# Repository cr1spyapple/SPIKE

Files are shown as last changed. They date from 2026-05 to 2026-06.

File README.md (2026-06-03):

# SPIKE
A sleek and speedy ESP32-S3 powered development board

Designed in KiCAD as part of STASIS for Hack Club. I took up this project to learn more about PCB and MCU design. This acts as a prototype of sorts to my e-Reader project <a href="https://github.com/cr1spyapple/Bebop">"Bebop"</a> which will use similar hardware to this.

## Specs:
- 32 GPIO pins
- 16MB flash
- 8MB PSRAM
- WiFi and Bluetooth connectivity
- USB-C port

## PCB Model
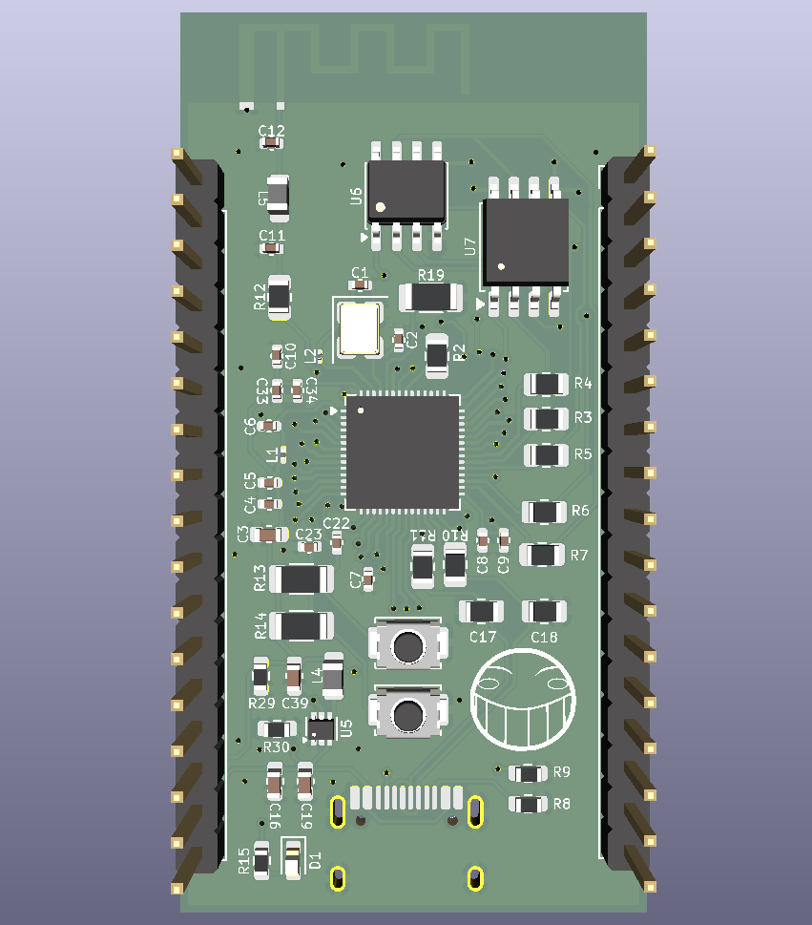
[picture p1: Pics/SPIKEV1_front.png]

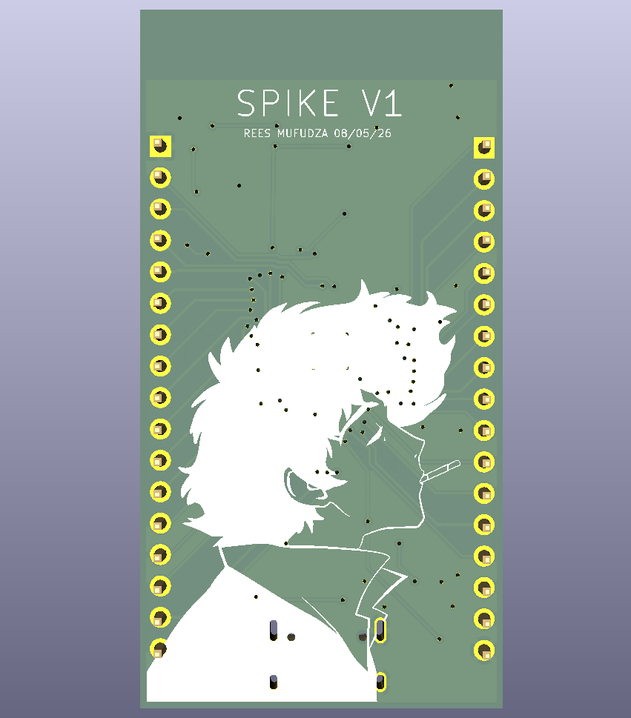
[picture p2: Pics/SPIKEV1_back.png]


## Schematic
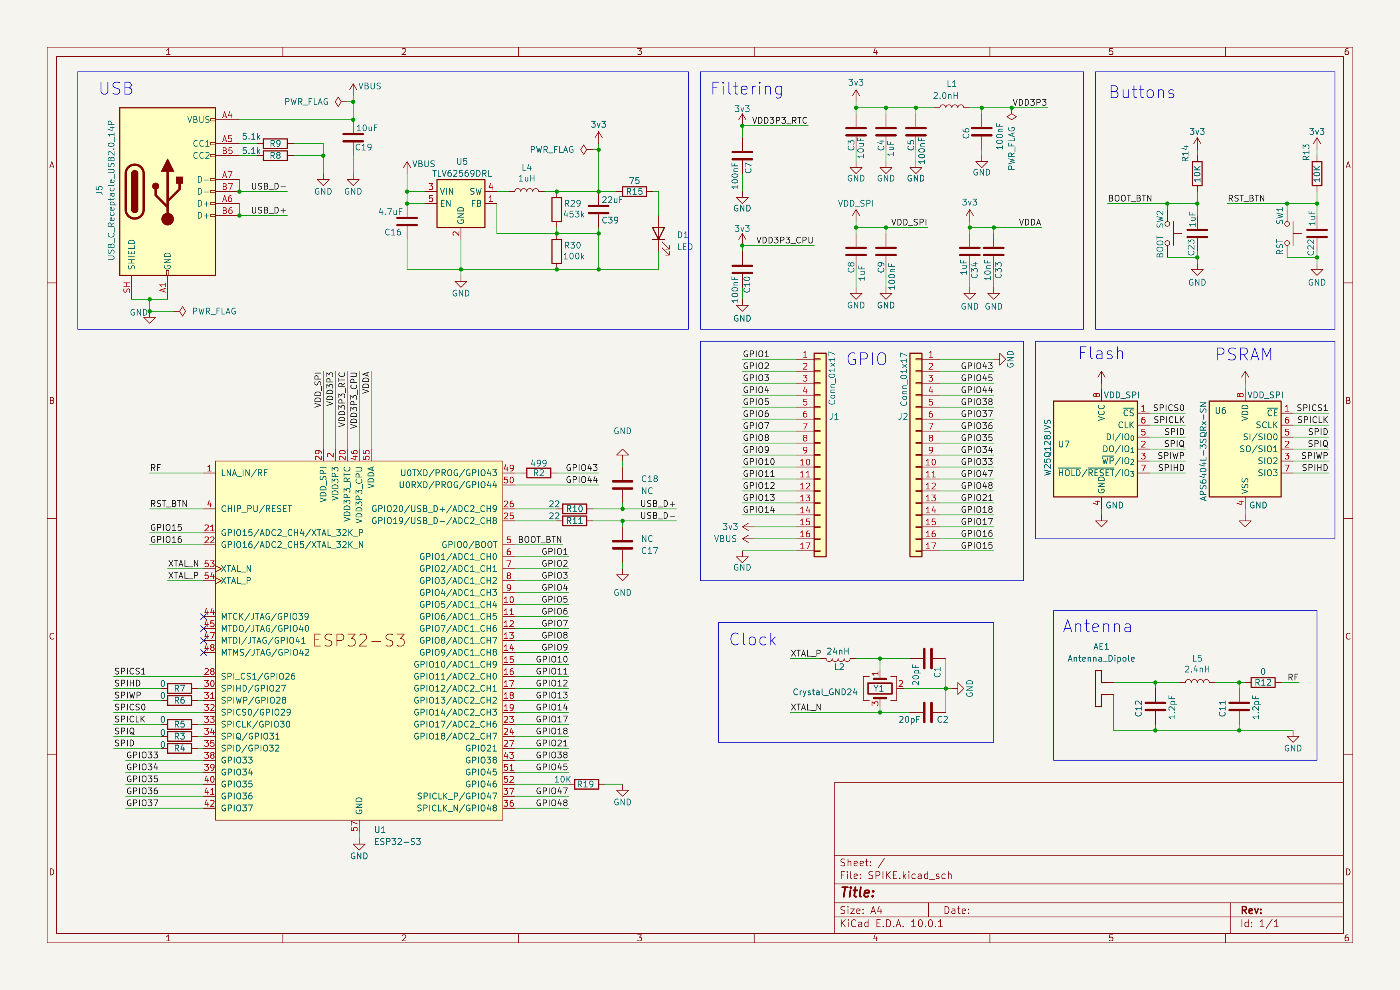
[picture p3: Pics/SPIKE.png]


## PCB Traces
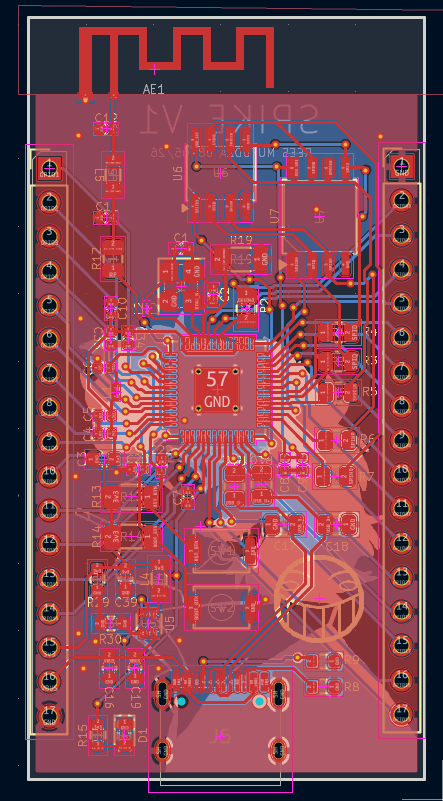
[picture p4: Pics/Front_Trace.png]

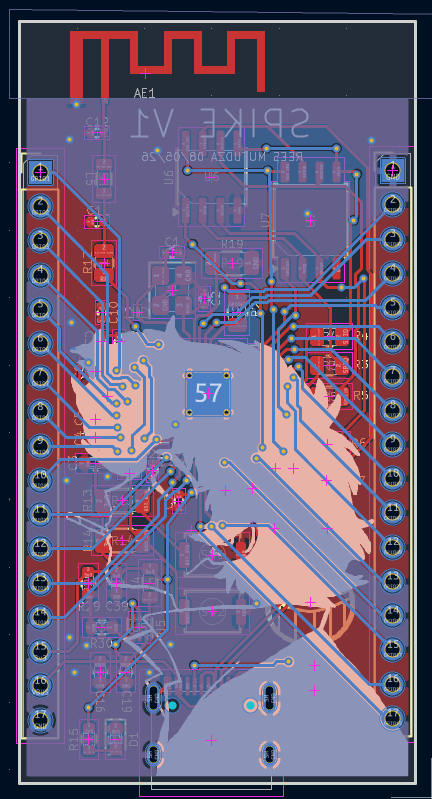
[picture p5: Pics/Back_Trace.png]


## Bill of Materials

|Name |Purpose |Quantity|Total Cost (USD)|Link |Distributor|
|---|---|---|---|---|---|
|10kΩ ±5% 100mW 0603 Thick Film Resistor | |100 |0.11 |https://www.lcsc.com/product-detail/C2930027.html | |
|1.2pF 50V Ceramic Capacitor C0G 0402 | |50 |1.79 |https://www.lcsc.com/product-detail/C76899.html | |
|100nF ±10% 16V Ceramic Capacitor X7R 0402 | |100 |0.16 |https://www.lcsc.com/product-detail/C60474.html | |
|1uF ±10% 16V Ceramic Capacitor X5R 0402 | |100 |0.38 |https://www.lcsc.com/product-detail/C29266.html | |
|20pF ±5% 50V Ceramic Capacitor C0G 0402 | |100 |0.57 |https://www.lcsc.com/product-detail/C76959.html | |
|2.7V~3.6V 128Mbit 133MHz SPI SOIC-8-208mil Memory (ICs) RoHS | |3 |7.92 |https://www.lcsc.com/product-detail/C97521.html | |
|2A 1uH ±20% 95mΩ 3.1A 0805 Fixed Inductors RoHS | |5 |1.05 |https://www.lcsc.com/product-detail/C1331798.html | |
|140mA 24nH ±3% 2.3Ω Thick Film Inductor 0201 Fixed Inductors RoHS | |100 |0.84 |https://www.lcsc.com/product-detail/C206441.html | |
|500mA 2nH 100mΩ 0603 Fixed Inductors RoHS | |50 |0.65 |https://www.lcsc.com/product-detail/C395081.html | |
|USB-C (USB TYPE-C) Receptacle Connector 16 Position Surface Mount | |5 |0.94 |https://www.lcsc.com/product-detail/C165948.html | |
|Red 645nm LED Indication - Discrete 2.4V 0603 | |100 |0.70 |https://www.lcsc.com/product-detail/C2286.html | |
|22uF ±20% 10V Ceramic Capacitor X5R 0603 | |10 |0.21 |https://www.lcsc.com/product-detail/C86295.html | |
|10nF ±10% 50V Ceramic Capacitor X7R 0603 | |100 |0.37 |https://www.lcsc.com/product-detail/C100042.html | |
|499Ω ±1% 62.5mW 0402 Thick Film Resistor | |100 |0.07 |https://www.lcsc.com/product-detail/C4125.html | |
|800mA 2.4nH 80mΩ Multilayer inductor 0402 Fixed Inductors RoHS | |10 |0.10 |https://www.lcsc.com/product-detail/C275281.html | |
|10uF ±20% 25V Ceramic Capacitor X5R 0603 | |20 |0.61 |https://www.lcsc.com/product-detail/C96446.html | |
|Crystal 40MHz ±10ppm 15pF SMD3225-4P | |10 |0.69 |https://www.lcsc.com/product-detail/C5444549.html | |
|SOP-8L Memory (ICs) RoHS | |2 |8.93 |https://www.lcsc.com/product-detail/C3028887.html | |
|1.5MHz Step-down type Adjustable 600mV~5.5V 2A SOT-563 Voltage Regulators - DC DC Switching Regulators RoHS| |5 |0.59 |https://www.lcsc.com/product-detail/C163217.html | |
|-98.4dBm 150Mbps 2.412GHz~2.484GHz 2.4GHz 3V~3.6V QFN-56-EP(7x7) RF Transceiver ICs RoHS | |3 |9.06 |https://www.lcsc.com/product-detail/C2913192.html | |
|Tactile Switch SPST 160gf 2mm SMD (SMT) Tab 4mm x 3mm Surface Mount | |10 |0.57 |https://www.lcsc.com/product-detail/C720477.html | |
|100mW 100kΩ 75V Thick Film Resistor ±100ppm/℃ ±1% 0603 Chip Resistor - Surface Mount RoHS | |100 |0.15 |https://www.lcsc.com/product-detail/C14675.html | |
|453kΩ ±0.1% 100mW 0603 Thin Film Resistor | |20 |0.48 |https://www.lcsc.com/product-detail/C2686428.html | |
|75Ω ±1% 100mW 0603 Thick Film Resistor | |100 |0.19 |https://www.lcsc.com/product-detail/C4275.html | |
|22Ω ±5% 100mW 0603 Thick Film Resistor | |100 |0.12 |https://www.lcsc.com/product-detail/C2907129.html | |
|5.1kΩ ±1% 100mW 0603 Thick Film Resistor | |100 |0.13 |https://www.lcsc.com/product-detail/C2907044.html | |
|0Ω 125mW 200V Thick Film Resistor 0805 Chip Resistor - Surface Mount RoHS | |100 |0.63 |https://www.lcsc.com/product-detail/C844934.html | |
|4.7uF ±10% 16V Ceramic Capacitor X5R 0603 | |10 |0.14 |https://www.lcsc.com/product-detail/C19666.html | |
|Header pins |Header pins for PCB |1 |1.98 |https://www.aliexpress.com/item/1005008703085861.html?search_p4p_id=202605091107184238603551627500001818552_9|Aliexpress |
|Soldering paste (20g) |Soldering components |1 |3.46 |https://www.aliexpress.com/item/1005009377104599.html?mp=1 |Aliexpress |
|Hot Plate |Soldering SMD components  |1 |13.99 |https://www.aliexpress.com/item/1005007016135854.html?mp=1 |Aliexpress |
|65W Type-C power adapter |Power supply for Hot Plate|1 |12.68 |https://www.ebay.co.uk/itm/406309629830 |Ebay |
|PCB |PCB |5 |4.10 | |JLCPCB |

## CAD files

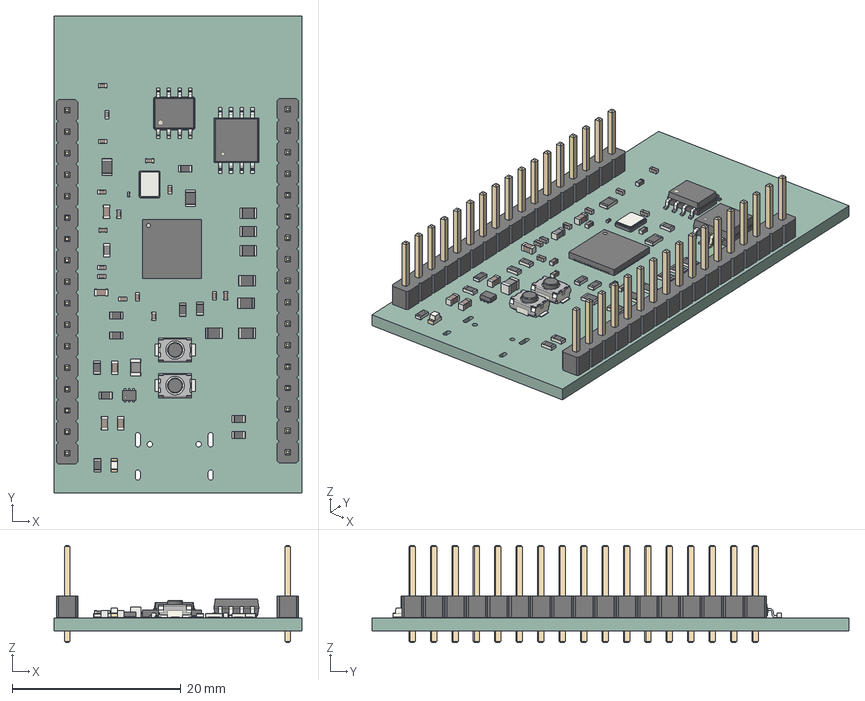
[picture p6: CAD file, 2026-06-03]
models/jett.step
29.3 x 56.5 x 11.5 mm
R_0805_2012Metric x 9
C_0603_1608Metric x 5
L_0805_2012Metric
R_0603_1608Metric x 10
a48c614c-8773-11ed-8f9d-58fb8493fcfb_part
a48c63fe-8773-11ed-8f9d-58fb8493fcfb_part
a48c65a2-8773-11ed-8f9d-58fb8493fcfb_part
a48c66d8-8773-11ed-8f9d-58fb8493fcfb_part
C_0402_1005Metric x 14
SW_Push_SPST_NO_Alps_SKRK x 2
LED_0603_1608Metric
L_0201_0603Metric
L_0603_1608Metric
PinHeader_1x17_P254mm_Vertical x 2
SOT_563
L_0402_1005Metric
Crystal_SMD_3225-4Pin_3.2x2.5mm
SOIC-8_3.9x4.9mm_P1.27mm
SOIC-8_5.3x5.3mm_P1.27mm
SPIKE_PCB

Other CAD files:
models/jett.stl

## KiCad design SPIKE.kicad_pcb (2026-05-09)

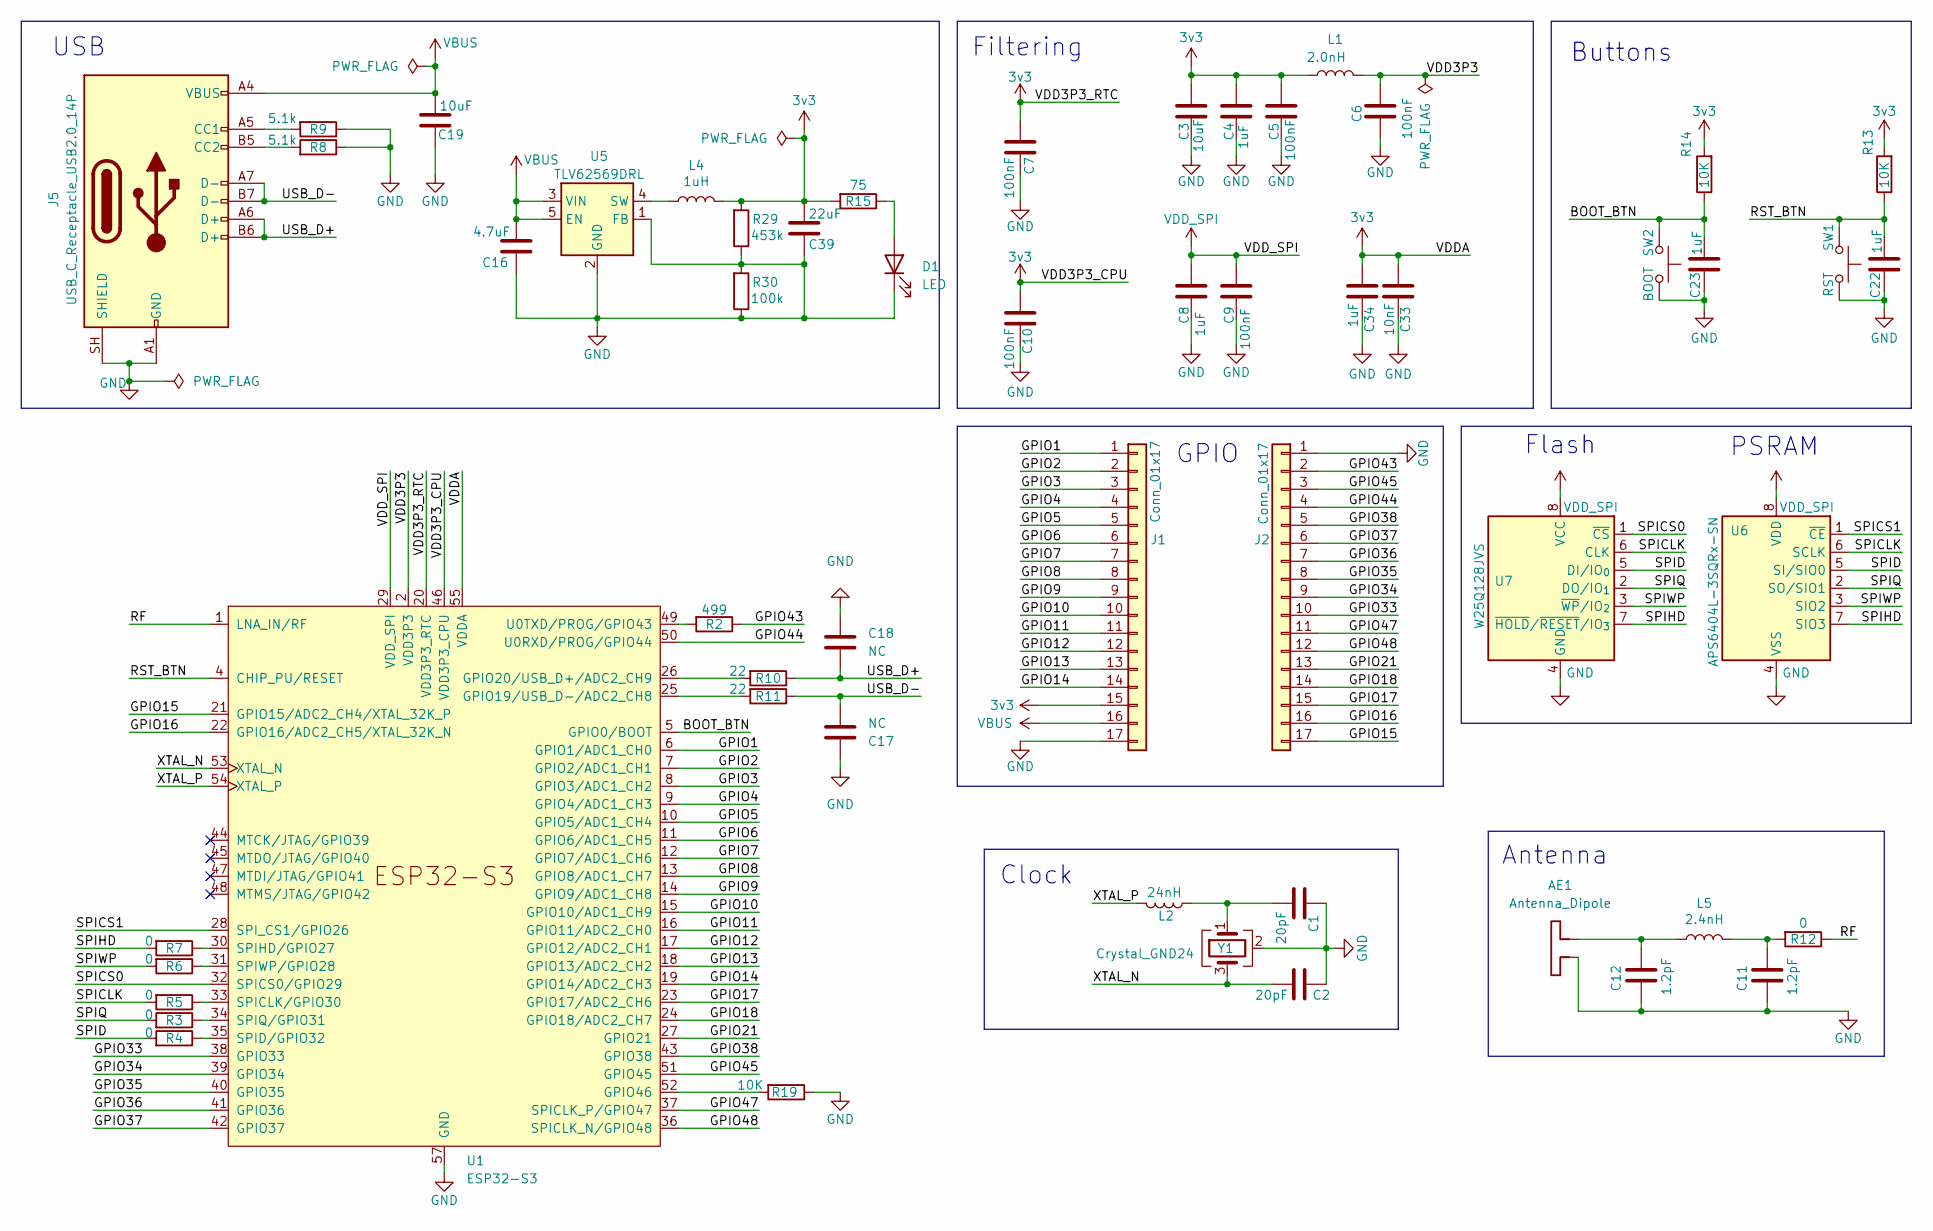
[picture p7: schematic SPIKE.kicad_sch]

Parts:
AE1: Antenna_Dipole; Trace Antenna 2.4GHz
C1, C2: 20pF; C_0402_1005Metric; MNF PART NUMBER C1554
C3, C19: 10uF; C_0603_1608Metric; MNF PART NUMBER C19702
C4, C8, C22, C23, C34: 1uF; C_0402_1005Metric; MNF PART NUMBER C52923
C5, C6, C7, C9, C10: 100nF; C_0402_1005Metric; MNF PART NUMBER C1591
C11, C12: 1.2pF; C_0402_1005Metric; MNF PART NUMBER C52923
C16: 4.7uF; C_0603_1608Metric; MNF PART NUMBER C19702
C17, C18: NC; R_0805_2012Metric
C33: 10nF; C_0603_1608Metric; MNF PART NUMBER C57112
C39: 22uF; C_0603_1608Metric; MNF PART NUMBER C19702
D1: LED; LED_0603_1608Metric; MFN PART NUMBER C2286
J1, J2: Conn_01x17; PinHeader_1x17_P2.54mm_Vertical
J5: USB_C_Receptacle_USB2.0_14P; USB_C_Receptacle_HRO_TYPE-C-31-M-12; MNF PART NUMBER C165948
L1: 2.0nH; L_0603_1608Metric; MNF PART NUMBER C370234
L2: 24nH; L_0201_0603Metric; MNF PART NUMBER C139271
L4: 1uH; L_0805_2012Metric; MNF PART NUMBER C19533
L5: 2.4nH; L_0805_2012Metric; MNF PART NUMBER C19533
R2: 499; R_0805_2012Metric; MNF PART NUMBER C17722
R3, R4, R5, R6, R7, R12: 0; R_0805_2012Metric; MNF PART NUMBER C17477
R8, R9: 5.1k; R_0603_1608Metric; MNF PART NUMBER C23186
R10, R11: 22; R_0603_1608Metric; MNF PART NUMBER C23345
R13, R14, R19: 10K; R_0603_1608Metric; MNF PART NUMBER C25804
R15: 75; R_0603_1608Metric; MNF PART NUMBER C4275
R29: 453k; R_0603_1608Metric; MNF PART NUMBER C101055
R30: 100k; R_0603_1608Metric; MNF PART NUMBER C25803
SW1: RST; SW_Push_SPST_NO_Alps_SKRK; MNF PART NUMBER C720477
SW2: BOOT; SW_Push_SPST_NO_Alps_SKRK; MNF PART NUMBER C720477
U1: ESP32-S3; QFN-56-1EP_7x7mm_P0.4mm_EP5.6x5.6mm; MNF PART NUMBER C2913192
U5: TLV62569DRL; SOT-563; MNF PART NUMBER C163217
U6: APS6404L-3SQRx-SN; SOIC-8_3.9x4.9mm_P1.27mm; MNF PART NUMBER C5333729
U7: W25Q128JVS; SOIC-8_5.3x5.3mm_P1.27mm; MNF PART NUMBER C97521
Y1: Crystal_GND24; Crystal_SMD_3225-4Pin_3.2x2.5mm; MNF PART NUMBER C9010

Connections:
3v3: C3.2, C4.2, C5.2, C7.2, C10.2, C33.2, C34.2, C39.2, J1.15, L1.1, L4.1, R13.2, R14.2, R15.2, R29.2, U1.20 (VDD3P3_RTC), U1.46 (VDD3P3_CPU), U1.55 (VDDA), U1.56 (VDDA)
/BOOT_BTN: C23.2, R14.1, SW2.1, U1.5 (GPIO0/BOOT)
/GPIO1: J1.1, U1.6 (GPIO1/ADC1_CH0)
/GPIO2: J1.2, U1.7 (GPIO2/ADC1_CH1)
/GPIO3: J1.3, U1.8 (GPIO3/ADC1_CH2)
/GPIO4: J1.4, U1.9 (GPIO4/ADC1_CH3)
/GPIO5: J1.5, U1.10 (GPIO5/ADC1_CH4)
/GPIO6: J1.6, U1.11 (GPIO6/ADC1_CH5)
/GPIO7: J1.7, U1.12 (GPIO7/ADC1_CH6)
/GPIO8: J1.8, U1.13 (GPIO8/ADC1_CH7)
/GPIO9: J1.9, U1.14 (GPIO9/ADC1_CH8)
/GPIO10: J1.10, U1.15 (GPIO10/ADC1_CH9)
/GPIO11: J1.11, U1.16 (GPIO11/ADC2_CH0)
/GPIO12: J1.12, U1.17 (GPIO12/ADC2_CH1)
/GPIO13: J1.13, U1.18 (GPIO13/ADC2_CH2)
/GPIO14: J1.14, U1.19 (GPIO14/ADC2_CH3)
/GPIO15: J2.17, U1.21 (GPIO15/ADC2_CH4/XTAL_32K_P)
/GPIO16: J2.16, U1.22 (GPIO16/ADC2_CH5/XTAL_32K_N)
/GPIO17: J2.15, U1.23 (GPIO17/ADC2_CH6)
/GPIO18: J2.14, U1.24 (GPIO18/ADC2_CH7)
/GPIO21: J2.13, U1.27 (GPIO21)
/GPIO33: J2.10, U1.38 (GPIO33)
/GPIO34: J2.9, U1.39 (GPIO34)
/GPIO35: J2.8, U1.40 (GPIO35)
/GPIO36: J2.7, U1.41 (GPIO36)
/GPIO37: J2.6, U1.42 (GPIO37)
/GPIO38: J2.5, U1.43 (GPIO38)
/GPIO43: J2.2, R2.1
/GPIO44: J2.4, U1.50 (U0RXD/PROG/GPIO44)
/GPIO45: J2.3, U1.51 (GPIO45)
/GPIO47: J2.11, U1.37 (SPICLK_P/GPIO47)
/GPIO48: J2.12, U1.36 (SPICLK_N/GPIO48)
/RF: R12.1, U1.1 (LNA_IN/RF)
/RST_BTN: C22.2, R13.1, SW1.1, U1.4 (CHIP_PU/RESET)
/SPICLK: R5.2, U6.6 (SCLK), U7.6 (CLK)
/SPICS0: U1.32 (SPICS0/GPIO29), U7.1 (~CS)
/SPICS1: U1.28 (SPI_CS1/GPIO26), U6.1 (~CE)
/SPID: R4.2, U6.5 (SI/SIO0), U7.5 (DI/IO_{0})
/SPIHD: R7.2, U6.7 (SIO3), U7.7 (~HOLD/~RESET/IO_{3})
/SPIQ: R3.2, U6.2 (SO/SIO1), U7.2 (DO/IO_{1})
/SPIWP: R6.2, U6.3 (SIO2), U7.3 (~WP/IO_{2})
/USB_D+: C18.2, J5.A6 (D+), J5.B6 (D+), R10.1
/USB_D-: C17.2, J5.A7 (D-), J5.B7 (D-), R11.1
/XTAL_N: C2.2, U1.53 (XTAL_N), Y1.3
/XTAL_P: L2.2, U1.54 (XTAL_P)
GND: AE1.1, C1.1, C2.1, C3.1, C4.1, C5.1, C6.1, C7.1, C8.1, C9.1, C10.1, C11.1, C12.1, C16.1, C17.1, C18.1, C19.1, C22.1, C23.1, C33.1, C34.1, C39.1, D1.1 (K), J1.17, J2.1, J5.A1 (GND), J5.A12 (GND), J5.B1 (GND), J5.B12 (GND), J5.SH (SHIELD), R8.1, R9.1, R19.1, R29.1, R30.1, R30.2, SW1.2, SW2.2, U1.57 (GND), U5.1 (FB), U5.2 (GND), U6.4 (VSS), U7.4 (GND), Y1.2 (G), Y1.4 (G)
unnamed: AE1.2, C12.2, L5.2
unnamed: C1.2, L2.1, Y1.1
unnamed: C11.2, L5.1, R12.2
unnamed: D1.2 (A), R15.1
unnamed: J5.A5 (CC1), R9.2
unnamed: J5.B5 (CC2), R8.2
unnamed: R11.2, U1.25 (GPIO19/USB_D-/ADC2_CH8)
unnamed: R10.2, U1.26 (GPIO20/USB_D+/ADC2_CH9)
unnamed: R19.2, U1.52 (GPIO46)
unnamed: R5.1, U1.33 (SPICLK/GPIO30)
unnamed: R4.1, U1.35 (SPID/GPIO32)
unnamed: R7.1, U1.30 (SPIHD/GPIO27)
unnamed: R3.1, U1.34 (SPIQ/GPIO31)
unnamed: R6.1, U1.31 (SPIWP/GPIO28)
unnamed: R2.2, U1.49 (U0TXD/PROG/GPIO43)
unnamed: L4.2, U5.4 (SW)
VBUS: C16.2, C19.2, J1.16, J5.A4 (VBUS), J5.A9 (VBUS), J5.B4 (VBUS), J5.B9 (VBUS), U5.3 (VIN), U5.5 (EN)
VDD3P3: C6.2, L1.2, U1.2 (VDD3P3), U1.3 (VDD3P3)
VDD_SPI: C8.2, C9.2, U1.29 (VDD_SPI), U6.8 (VDD), U7.8 (VCC)

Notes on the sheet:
Flash
USB
Clock
Antenna
GPIO
Filtering
PSRAM
Buttons

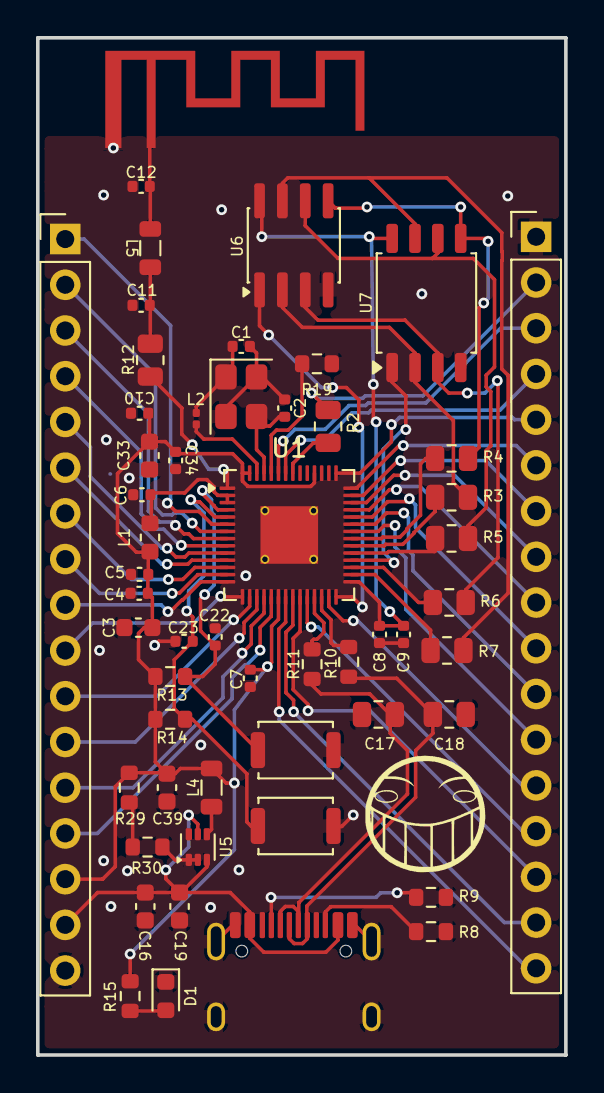
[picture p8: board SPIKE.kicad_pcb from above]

Board: 2 copper layers, 29.3 x 56.5 mm, 56 parts (1 on the bottom side), 65 nets.

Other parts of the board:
Back: LOGO; Spike_manga
Front: LOGO; ED_smile

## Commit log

2026-05-09 Upload gerbers and some modifications
    [SPIKE.kicad_pcb, SPIKE.kicad_sch]
2026-05-15 Added bill of materials
    [SPIKE-bom.csv]
